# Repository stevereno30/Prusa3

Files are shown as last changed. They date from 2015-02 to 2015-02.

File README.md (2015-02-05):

# This is Prusa iteration 3 - ANSI Edition
Published under GPL v3

This Prusa3 fork has two main goals:

1. Make every part parametric that can be parametric.
2. Replace all metric bolts with ANSI bolts (when possible)

Parts that have been made parametric are the following:
  -all nut traps/slots! Change the nut_diameter setting in metric.scad and the nut_diameter_horizontal changes dynamically!
  -x-end (see below)
  
Changes from vanilla:
  -The bearing-guide.scad was modified slightly so the bearing guides do not increase the overall diameter of the idler assembly so dramatically.
  -The x-end that holds the x-idler dynamically changes when you set your bearings in configuration.scad. 608 bearings now interface with the idler/x-end even with bearing guides attached!

All models are in the box_frame folder, including models for aluminium single plate. For my particular vitamins (hardware), STLs were saved and can be found in box_frame/sample_stls.

If you are looking for models that josefprusa uses in workshops, you need to go to https://github.com/josefprusa/Prusa3-vanilla

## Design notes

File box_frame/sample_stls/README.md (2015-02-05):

# Default box version
These STL files are calibrated for my exact machine! Don't use these unless your vitamins match those in the list below!
All metric bolts (except those for mounting the NEMA17 motors) have been replaced with ANSI machine screws (that is, the illogical and confusing standard measurements used in the USA)

*For simplicities sake, the only thread size used was #6 (6-32 machine screws/nuts).*

The following screws are needed to assemble this printer:
* 4x 2" screws (two for mounting the extruder, two for the extruder idler)
* 14x 1.25" screws (four for the headed bed, ten for the bearing mounts)
* 7x 1" screws (four for the belt tensioners, three for the endstop mounts)
* 6x 0.5" screws (for endstops)
* 11x 3mm x 10mm bolts for the motor mounts (six for the z-axis, three for the x-axis, and two for the y-axis)

You will also need the following misc hardware:
* 31x 6-32 nuts (one for each of the screws above)
* 2x m6 nuts (for the z-axis... I had to use m6 because I couldn't source m5 threaded rod)
* 1x m8 nylon lock nut (for the hobbed bolt)
* 2-5 washers that fit snug around your hobbed bolt(for adjusting the position of your hobbed bolt's hobs)
* 6x stiff springs (two for your extruder idler, four for your heated bed)
* 12x 6-32 compatible washers (to contain the springs on your heated bed and extruder idler)
* 34x 3/8 nuts (for the y-axis threaded rods, which is what I used for my printer since they are a fraction of the cost of M10 rods)
* 5x 608zz bearings (two for the extruder, one for the extruder idler, one for the x-idler and one for the y-idler)
* OPTIONAL 34x 3/8 washers (To go between your y-axis nuts and the printed parts)

From variable vitamins you need 2x *gt2 Pulley with 18-30 teeth*, and GT2 belts. The linear bearings are all *lm10uu* (10x) and smooth rods have diameter of 5/16in.

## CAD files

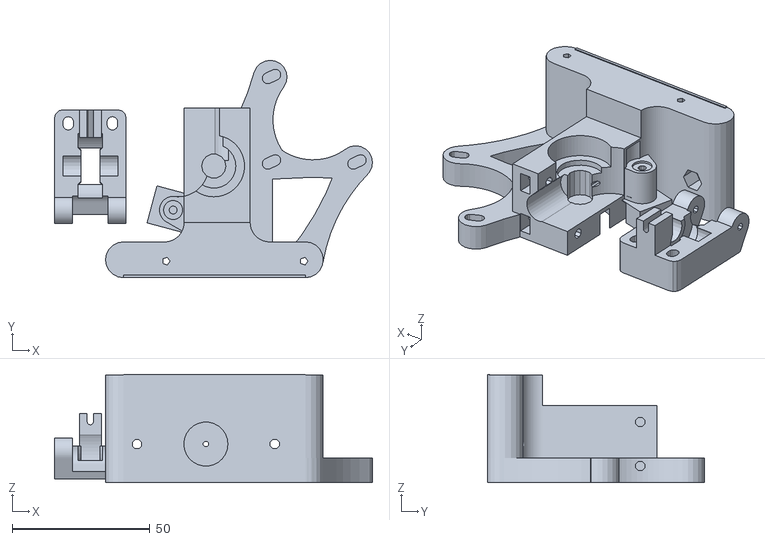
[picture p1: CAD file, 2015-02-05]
box_frame/sample_stls/extras/gregs-wade-v3.stl
115.4 x 78.9 x 39.3

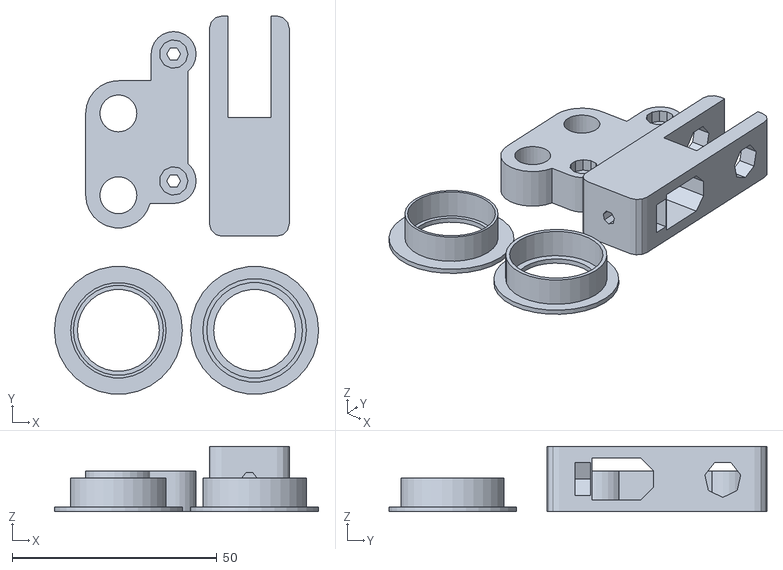
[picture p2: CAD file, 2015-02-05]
box_frame/sample_stls/y-drivetrain.stl
64.6 x 92.4 x 16.0

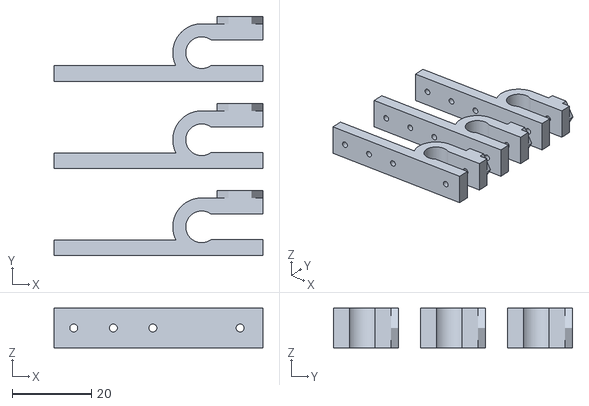
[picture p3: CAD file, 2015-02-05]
box_frame/sample_stls/extras/endstop-holder.stl
52.8 x 60.5 x 10.0

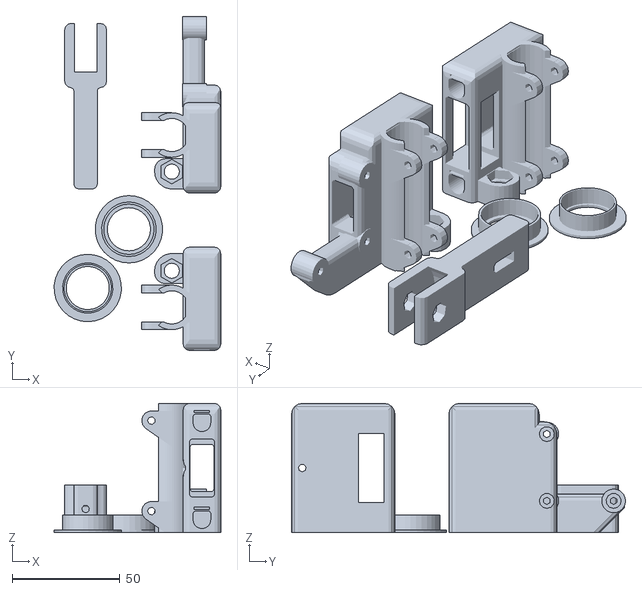
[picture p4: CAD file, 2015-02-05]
box_frame/sample_stls/x-end.stl
77.3 x 155.0 x 60.0

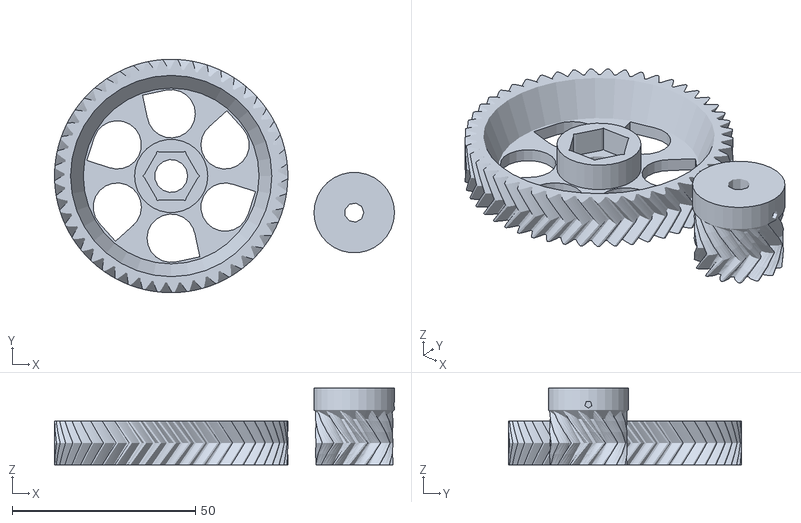
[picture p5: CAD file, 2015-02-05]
box_frame/sample_stls/extras/wade-gears.stl
92.9 x 63.7 x 21.0

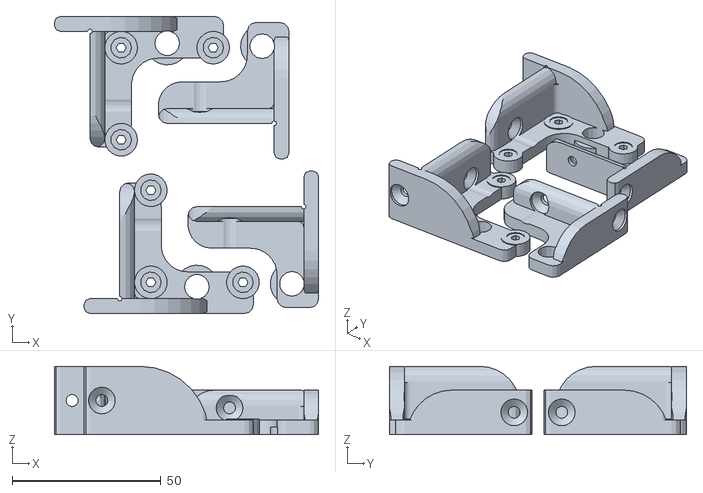
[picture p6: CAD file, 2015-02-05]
box_frame/sample_stls/z-axis.stl
89.0 x 100.0 x 23.0

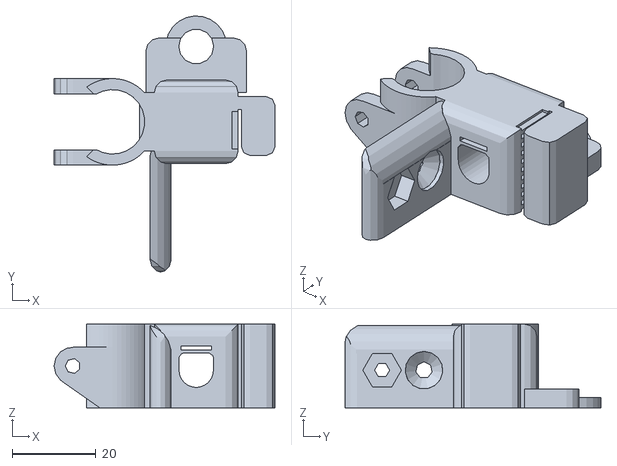
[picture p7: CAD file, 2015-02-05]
box_frame/sample_stls/extras/calibrate.stl
52.8 x 61.1 x 20.0

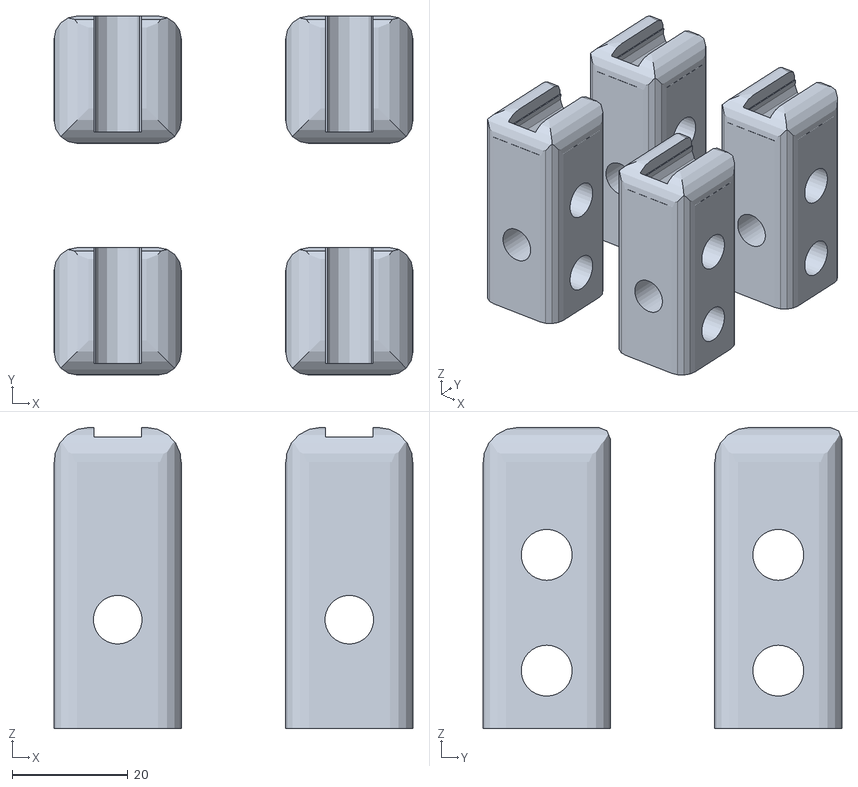
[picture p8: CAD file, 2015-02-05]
box_frame/sample_stls/y-axis-corner.stl
62.0 x 62.0 x 52.0

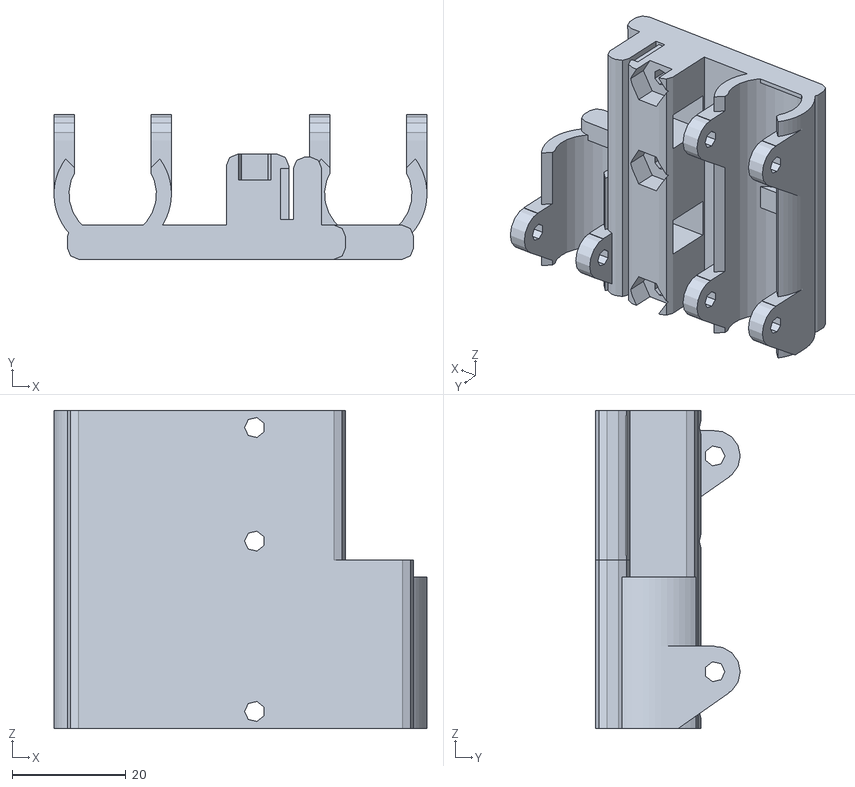
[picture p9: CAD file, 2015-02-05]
box_frame/sample_stls/x-carriage.stl
65.7 x 25.4 x 56.0

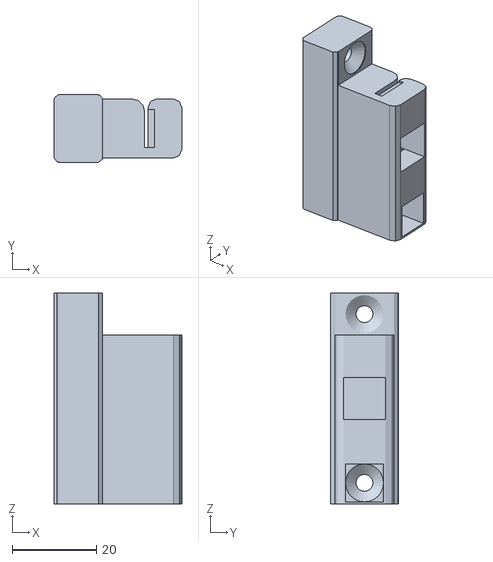
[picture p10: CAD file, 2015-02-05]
box_frame/sample_stls/y-belt-holder.stl
30.2 x 16.0 x 50.0

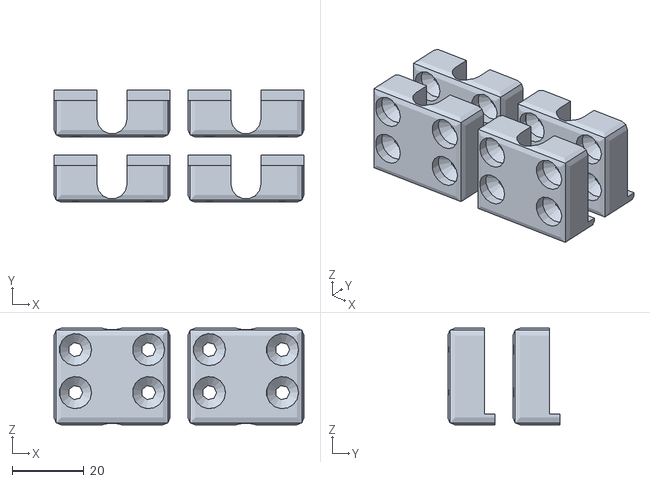
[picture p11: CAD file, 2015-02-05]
box_frame/sample_stls/y-axis-bracket.stl
69.8 x 31.4 x 27.0

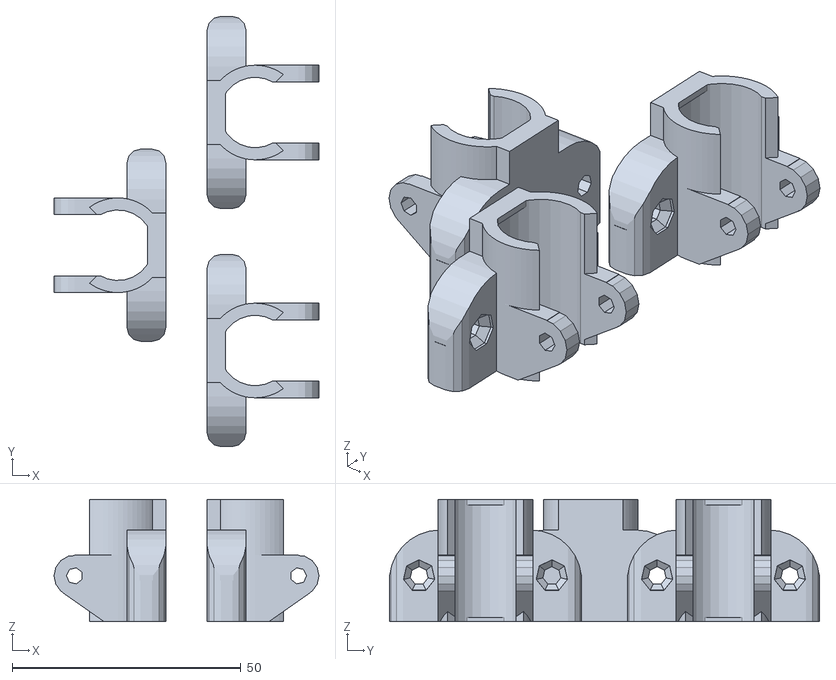
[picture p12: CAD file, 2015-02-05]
box_frame/sample_stls/bushing.stl
57.9 x 94.0 x 26.7

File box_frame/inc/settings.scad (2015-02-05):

// Moved from config.scad

board_to_xz_distance = 26;
xaxis_rod_distance = 45;

//calculated from settings
single_wall_width = width_over_thickness * layer_height;

idler_width = max(belt_width, (idler_bearing[1] > 7 ? idler_bearing[1] : 7)) + 2.5 * idler_bearing[3] ;

//deltas are used to enlarge parts for bigger bearings
xy_delta = ((bushing_xy[1] <= 7.7) ? 0 : bushing_xy[1] - 7.7) * 0.9;
z_delta = (bushing_z[1] <= 7.7) ? 0 : bushing_z[1] - 7.7;

m3_nut_diameter_bigger = ((440_nut_diameter / 2) / cos (180 / 6)) * 2;

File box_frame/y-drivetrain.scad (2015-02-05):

// PRUSA iteration3
// Y drivetrain (idler and stepper holders)
// GNU GPL v3
// Josef Průša <josefprusa@me.com>
// Václav 'ax' Hůla <axtheb@gmail.com>
// http://www.reprap.org/wiki/Prusa_Mendel
// http://github.com/josefprusa/Prusa3

// ThingDoc entry
/**
 * @id yMotorHolder
 * @name Y Axis Motor Holder
 * @category Printed
 */
 
/**
 * @id yIdler
 * @name Y Axis Belt Idler
 * @category Printed
 */ 
 
include <configuration.scad>
use <inc/bearing-guide.scad>

module motorholder(thickness=10){
    difference(){
        union(){
            // Motor holding part
            translate([29, -21 + 50, 0])
            {
                difference(){
                    union(){
                        translate([-21 + 4.5, 0, 5]) cube([9, 31, thickness], center=true);
                        nema17([0, 1, 1, 0], thickness=thickness, shadow=false);
                        mirror([0, 0, 1]) translate([0, 0, -10]) nema17([0, 1, 1, 0], thickness=thickness, shadow=7);
                        // Parts joining part
                        translate([-29, -21, 0]) cube([14, 30, thickness]);
                    }
                    // Motor mounting holes
                    translate([0, 0, thickness]) mirror([0, 0, 1]) nema17([0, 1, 1, 0], thickness=thickness, holes=true);
                }
            }

            // Front holding part
            translate([0, 10, 0]) cylinder(h = thickness, r=8);
            translate([0, 20, 5]) cube([16, 20, thickness], center=true);
            translate([0, 30, 0]) cylinder(h = thickness, r=8);
        }
        translate([0, 10, -1]) cylinder(h = 12, r=4.5, $fn=32);
        translate([0, 30, -1]) cylinder(h = 12, r=4.5, $fn=32);
    }
}

module oval(r=4, l=14, h=2){
    intersection() {
        union() {
            translate([l / 2, 0, 0]) cylinder(r=r, h=h, $fn=4);
            //translate([-l / 2, 0, 0]) cylinder(r=r, h=h, $fn=4);
            translate([0, 0, h / 2]) cube([l, r * 2, h], center=true);
        }
        translate([0, 0, h / 2]) cube([l + r * 1.2, r * 2, h], center=true);
    }
}

module idlermount(len=45, narrow_len=0, narrow_width=0, rod=threaded_rod_diameter_horizontal / 2, idler_height=16){
    difference(){
        union(){
            //wide part holding bearing
            translate([- (10 + idler_width) / 2, -25 + narrow_len, 0] ) cube_fillet([10 + idler_width, len + idler_bearing[2] * 1.1 - narrow_len, idler_height]);
            //For X there is narrow part inside the x-idler
            if (narrow_len > 0){
                translate([-narrow_width / 2, -25, 0] ) cube_fillet([narrow_width, len + idler_bearing[2], idler_height], vertical=[0, 0, 2, 2]);
                mirror([1, 0, 0]) translate([-narrow_width / 2, narrow_len -25, idler_height / 2 ]) fillet(1.5, idler_height - 0.04, $fn=8);
                translate([-narrow_width / 2, narrow_len -25, idler_height / 2]) fillet(1.5, idler_height - 0.04, $fn=8);
            }
        }
        translate([-12, -8, idler_height / 2]) rotate([90, 0, 90]) oval(r=rod + 0.01, l=12, h=25);
        translate([0, -13 - single_wall_width*2, idler_height / 2]) {
            // nut for tensioning screw
            translate([0,0,0]) rotate([90, 0, 0]) cylinder(r=632_nut_diameter_horizontal / 2, h=3.8, $fn=6);

            // nut insert
            translate([-2, -3.8, - 632_nut_diameter / 2 ]) cube([20, 3.8, 632_nut_diameter ]);
        }

        // tensioning screw goes here
        translate([0, -19, idler_height / 2]) rotate([90, 90, 0]) cylinder(r=632_diameter / 2, h=15, $fn=small_hole_segments, center=true);
        // bearing goes there
        translate([0, len + idler_bearing[2] - 35, idler_height / 2]) {
            rotate([0, 90, 0]) idler_assy(idler_bearing);
            translate([0, 10, 0]) cube([idler_width + 1, 20, idler_height + 2], center=true);
        }

    }
}


motorholder();
translate([32, 25, 0])  idlermount();

if (idler_bearing[3] == 1) {
    translate([0, -12 - idler_bearing[0] / 2, 0]) {
        render() bearing_assy();
    }
}

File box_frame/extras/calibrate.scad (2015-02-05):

// PRUSA iteration3
// Calibrating object
// GNU GPL v3
// Václav 'ax' Hůla <axtheb@gmail.com>

include <../configuration.scad>
use <../bushing.scad>

use <../x-end.scad>

intersection() {
    difference() {
        union(){
            //central cube
            translate([-10, -10, 0]) cube_fillet([20, 20, 20], top=[3, 0, 3, 0]);
            //xy bearing. If the bearing is hard to put inside you are probably extruding too much fabric.
            mirror([1, 0, 0]) translate([20, 0, 0]) linear_bearing();
            //z smooth rod. See note above. You can adjust it in inc/conf_bushing.scad, but the problem is likely to be in machine.
            translate([-12, 7, 0]) cube_fillet([24, 13, 4.5], vertical=[3, 3, 0, 0]);
            translate([0, 18, 0]) cylinder(h=2.5, r=(bushing_z[0] + 5 * single_wall_width));
            //z wall
            translate([-11, -36, 0]) cube_fillet([5, 31, 20], top=[0, 0, 5, 7]);
            //belt holder. Belt thickness is in configuration.scad
            translate([14 + belt_thickness, -1, 10]) cube_fillet([8, 14, 20], center = true, vertical = [2,0,2,2], fn=8);
            translate([5, 3, 0]) cube ([10, 3, 20]);

        }

        //xy bearing hole
        mirror([1, 0, 0]) translate([20, 0, 0]) linear_bearing_negative();
        //x smooth rod
        translate([0, -11, 5 + bushing_xy[0]]) rotate([-90, 0, 0]) pushfit_rod(bushing_xy[0] * 2 + 0.2, 50);
        //z smooth rod
        translate([0, 18, -1]) cylinder(h=20, r=bushing_z[0] + single_wall_width / 4);

        //screw
        translate([0, -17, 9]) rotate([0, -90, 0]) screw(head_drop=7, h=122, r_head=4.5);
        //x carriage nut. Too bad its not parametrised (todo)
         translate([-7,-27, 9]) rotate([90, 0, 0]) {
            rotate([0, 90, 0]) cylinder(r=632_nut_diameter_horizontal / 2, h=5, $fn=6, center=true);
            rotate([0, 90, 0]) cylinder(r=632_diameter / 2, h=22, center=true);

        }
        //belt
        translate([10, -2, 0]) belt(25);
        #translate([10, -2, 0]) belt(25);


    }
    //Cut top to save plastic
    translate([-50, -50, 0]) cube([100, 100, 20]);
}

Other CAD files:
box_frame/extras/calibrateBOLTS.scad
box_frame/bushing.scad
box_frame/extras/gregs-wade-v3.scad
box_frame/inc/bearing-guide.scad
box_frame/inc/functions.scad
box_frame/inc/metric.scad
box_frame/x-carriage.scad
box_frame/x-end.scad

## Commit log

2015-02-05 Deleted Original .scad files
    [bearing-guide.scad, bushing.scad, calibrate.scad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]
2015-02-05 Update configuration.scad.dist
    Added "z_threaded_rod_diameter" for adjusting x-end nut dimensions
2015-02-05 Update x-end.scad
    Removed broken and commented code from line 125.
    [x-end.scad]
